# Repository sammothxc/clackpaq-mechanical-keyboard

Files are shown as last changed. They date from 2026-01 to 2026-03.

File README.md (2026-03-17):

CLACKPAQ
CLACKPAQ

A drop-in replacement mechanical keyboard for the Compaq Portable I/Plus foam and foil keyboard

## Specifications

- Controller: RP2040
- Switches: MX Cherry/Gateron Brown
- Keycaps: [Carbon PBT Double Shot Retro Orange](https://www.amazon.com/dp/B0D14Z76RH)
- Plate: FR4
- PCB: FR4, 2 layer, Hot-swappable
- Backlit

## Layout

### Modern

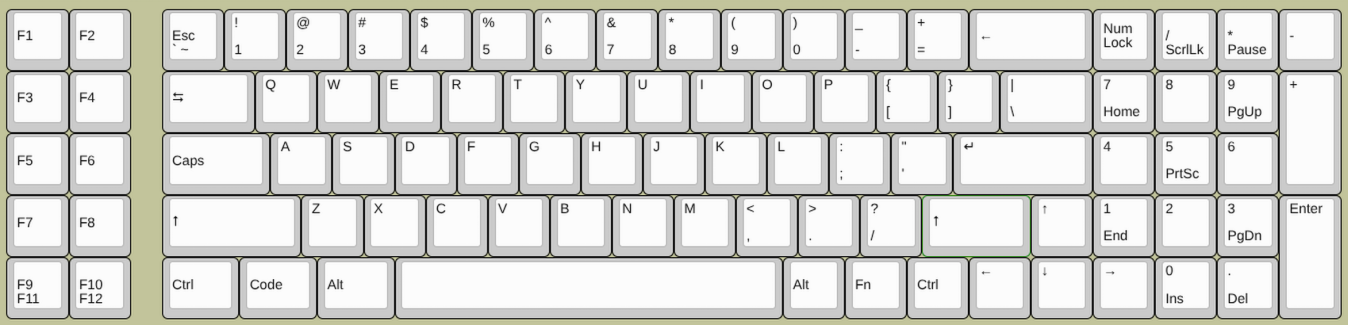
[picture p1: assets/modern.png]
Modern


### Compatible

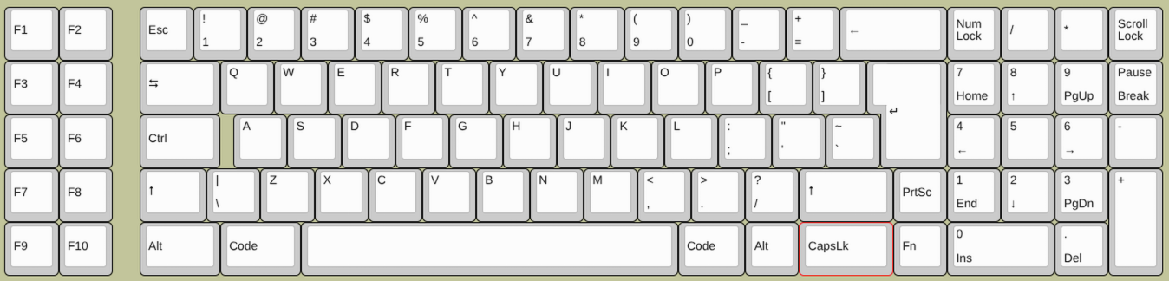
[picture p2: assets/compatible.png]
Compatible


### Original

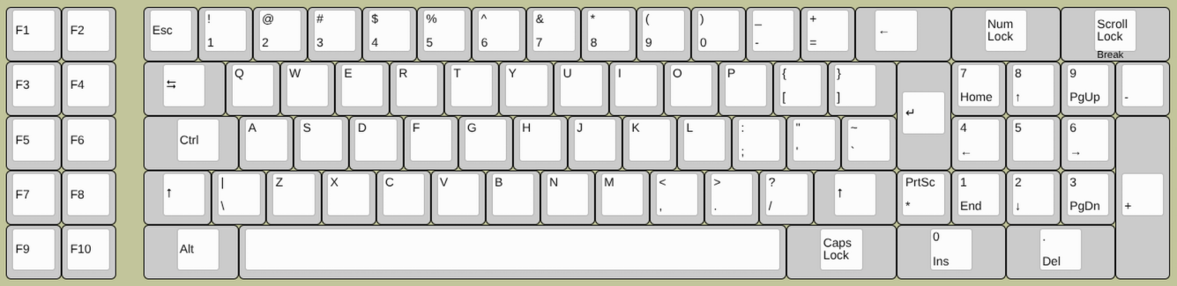
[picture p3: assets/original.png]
Original


### Spacing Differences
Original Keyboard Length: 18.75u / 357.18mm
Modern/Compatible Keyboard Layout Lengths: 10u / 361.95mm
Difference: 0.25u / 4.77mm

Row Specific Key Spacings
- Row 1
  - Total spacing w/ 18 keys (19 spaces): mm
  - Key Spacing: mm
- Row 2
  - 18 keys (19 spaces): mm
  - Key Spacing: mm
- Row 3
  - 17 keys (18 spaces): mm
  - Key Spacing: mm
- Row 4
  - 17 keys (18 spaces): mm
  - Key Spacing: mm
- Row 5
  - 13 keys (14 spaces): mm
  - Key Spacing: mm

## Pipe Dreams:
- Plates of other materials
- Acoustic foam

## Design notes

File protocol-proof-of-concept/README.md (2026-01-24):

# Clackpaq Firmware BETA

This firmware emulates the original Compaq Portable keyboard protocol, allowing you to send keystrokes to a Compaq Portable I or Portable Plus via serial commands.

## Hardware

**MCU:** Arduino Nano (ATmega328P @ 16MHz)
**Connections:**
  - D3 → CLK
  - D2 → DATA
  - GND → GND

## Protocol

Based on IBM PC/XT keyboard protocol with Compaq-specific timing:

- Idle state: CLK=HIGH, DATA=HIGH
- 9 bits per transmission: 1 start bit (always HIGH) + 8 data bits (LSB first)
- Host reads DATA on CLK falling edge
- Timing: ~358µs per byte transmission

## Serial Commands

| Command | Description |
|---|---|
| `BAT` | Send BAT completion code (0xAA) |
| `TEST` | Send 'A' key press and release |
| `SCOPE` | Send Enter make code (for oscilloscope testing) |
| `ENTER` | Send Enter key press and release |
| `MAKE xx` | Send make code (hex) |
| `BREAK xx` | Send break code (hex) |
| `RAW xx` | Send raw byte (hex) |
| `<text>` | Type text and press Enter |

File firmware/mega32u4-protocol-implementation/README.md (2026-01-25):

# Protocol Test Keyboard Matrix

Compaq Portable 1/Plus keyboard protocol emulator using a test keyboard matrix

## Hardware

- **MCU:** Elite-C ATmega32U4 (Pro Micro compatible)
- **Matrix:** 7 rows, 10 columns, 67 keys
- **XT Protocol Output:** 
  - CLK: Pin C6
  - DATA: Pin D4

## Pin Mapping

### Rows
| Row | Pin |
|-----|-----|
| 1 | F7 (A0) |
| 2 | B1 (15) |
| 3 | B2 (16) |
| 4 | F5 (A2) |
| 5 | F6 (A1) |
| 6 | F4 (A3) |
| 7 | B3 (14) |

### Columns
| Col | Pin |
|-----|-----|
| 1 | E6 (7) |
| 2 | B4 (8) |
| 3 | B5 (9) |
| 4 | B7 (11) |
| 5 | D5 |
| 6 | C7 (5) |
| 7 | F1 (A4) |
| 8 | F0 (A5) |
| 9 | B6 (10) |
| 10 | B0 |

### XT Interface
| Signal | Pin |
|---|-----|
| CLK | C6 (5) |
| DATA | D4 (4) |
| GND | GND |

## Keymap

### Base Layer
Standard QWERTY layout with:
- Arrow keys (Up/Down/Left/Right)
- Home, End, Page Up, Page Down
- Function key (Fn) for layer switching

### Function Layer (Fn+)
- Fn + 1-0 = F1-F10
- Fn + ~ = Escape  
- Fn + Backspace = Delete
- Fn + Home = Print Screen
- Fn + Caps = Scroll Lock

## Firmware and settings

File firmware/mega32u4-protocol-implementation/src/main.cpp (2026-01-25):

/*
* Protocol Test Keyboard Matrix
* For Elite-C Pro Micro (ATmega32U4)
* 
* Scans a 7x10 key matrix and outputs XT scancodes
* 
* License: CC BY-NC-SA 4.0
* https://github.com/sammothxc/clackpaq
*/

#include <Arduino.h>
#include "config.h"

// state vars
uint8_t keyState[ROWS][COLS];          // current debounced state
uint8_t lastKeyState[ROWS][COLS];      // previous state for edge detection
uint32_t lastDebounceTime[ROWS][COLS]; // debounce timers
bool fnPressed = false;                // fn layer active

// line control, open collector style
inline void clkHigh() {
  pinMode(XT_CLK, INPUT_PULLUP);
}

inline void clkLow() {
  pinMode(XT_CLK, OUTPUT);
  digitalWrite(XT_CLK, LOW);
}

inline void dataHigh() {
  pinMode(XT_DATA, INPUT_PULLUP);
}

inline void dataLow() {
  pinMode(XT_DATA, OUTPUT);
  digitalWrite(XT_DATA, LOW);
}

inline bool readClk() {
  pinMode(XT_CLK, INPUT_PULLUP);
  return digitalRead(XT_CLK);
}

void xt_write(uint8_t value, bool isBreak) {
  // wait for host to release CLK (not inhibiting)
  uint16_t timeout = 10000;
  while (!readClk() && timeout--) {
    delayMicroseconds(10);
  }
  if (timeout == 0) {
    Serial.println(F("Timeout: CLK held low by host"));
    return;
  }

  // ensure idle state
  clkHigh();
  dataHigh();
  delayMicroseconds(10);
  clkLow();
  delayMicroseconds(T_FIRST_CLK_LOW);

  // prep bit 0
  if (value & 0x01) {
    dataHigh();
  } else {
    dataLow();
  }
  clkHigh();
  value >>= 1;
  delayMicroseconds(T_CLK_HIGH);
    
  for (uint8_t i = 0; i < 7; i++) {
    clkLow();
    delayMicroseconds(T_CLK_LOW);

    // prep next bit
    if (value & 0x01) {
      dataHigh();
    } else {
      dataLow();
    }
    clkHigh();
    value >>= 1;
    delayMicroseconds(T_CLK_HIGH);
  }

  clkLow();
  delayMicroseconds(T_CLK_LOW);

  // DATA goes LOW for post-transmission hold
  dataLow();
  clkHigh();
    
  if (isBreak) {
    delayMicroseconds(T_POST_BREAK); // 500us for break codes
  } else {
    delayMicroseconds(T_POST_MAKE); // 640us for make codes
  }

  // return to idle
  dataHigh();
  delayMicroseconds(T_INTER_BYTE);
}

// wrappers
void xt_make(uint8_t scancode) {
    if (scancode == SC_NONE || scancode == SC_FN) return;
    xt_write(scancode, false);
}

void xt_break(uint8_t scancode) {
    if (scancode == SC_NONE || scancode == SC_FN) return;
    xt_write(scancode | 0x80, true);
}

void initMatrix() {
  for (uint8_t r = 0; r < ROWS; r++) {
    pinMode(rowPins[r], INPUT_PULLUP);
  }
  
  for (uint8_t c = 0; c < COLS; c++) {
    pinMode(colPins[c], INPUT_PULLUP);
  }
  
  for (uint8_t r = 0; r < ROWS; r++) {
    for (uint8_t c = 0; c < COLS; c++) {
      keyState[r][c] = 0;
      lastKeyState[r][c] = 0;
      lastDebounceTime[r][c] = 0;
    }
  }
}

void scanMatrix() {
  uint32_t now = millis();
  
  for (uint8_t r = 0; r < ROWS; r++) {
    pinMode(rowPins[r], OUTPUT);
    digitalWrite(rowPins[r], LOW);
    delayMicroseconds(5); // roughly the settle time
    
    for (uint8_t c = 0; c < COLS; c++) {
      uint8_t keyNum = keyMatrix[r][c];
      if (keyNum == 0) continue; // skip NC
      
      uint8_t reading = !digitalRead(colPins[c]);
      if (reading != lastKeyState[r][c]) {
        lastDebounceTime[r][c] = now;
      }
      
      if ((now - lastDebounceTime[r][c]) > DEBOUNCE_MS) {
        // state has been stable enough
        if (reading != keyState[r][c]) {
          keyState[r][c] = reading;
          
          uint8_t scancode;
          if (fnPressed && keyToScancodesFn[keyNum] != SC_NONE) {
            scancode = keyToScancodesFn[keyNum];
          } else {
            scancode = keyToScancode[keyNum];
          }
          
          // deal with fn key
          if (keyNum == 63) {
            fnPressed = reading;
          }
          else if (reading) {
            xt_make(scancode);
          } else {
            xt_break(scancode);
          }
        }
      }
      lastKeyState[r][c] = reading;
    }
    pinMode(rowPins[r], INPUT_PULLUP);
  }
}

void setup() {
  Serial.begin(9600);
  clkHigh();
  dataHigh();
  initMatrix();
  Serial.println(F("Clackpaq Keyboard Matrix Test Firmware"));
  delay(1000);
  xt_write(0xAA, false);
  Serial.println(F("Sent BAT (0xAA)"));
}

void loop() {
  // check if host is holding CLK low for >12.5ms, reset request
  if (!readClk()) {
    delay(15);
    if (!readClk()) {
      Serial.println(F("Host reset"));
      while (!readClk());
      delay(300);
      xt_write(0xAA, false);
    }
  }
  scanMatrix();
}

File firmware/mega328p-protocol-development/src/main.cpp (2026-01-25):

/*
* Protocol Proof of Concept
* For Arduino Nano (ATmega328P)
* 
* Based on oscilloscope captures and IBM 5155 Technical Reference
*
* License: CC BY-NC-SA 4.0
* https://github.com/sammothxc/clackpaq
*/

#include <Arduino.h>

#define XT_CLK  3
#define XT_DATA 2

// timing constants in microseconds
// adjusted for arduino overhead, target 358us total transmission
// digitalWrite/pinMode adds ~4-5us overhead per call, wish I could bitbang this stuff
#define T_FIRST_CLK_LOW   28    // first CLK pulse low time (target 42us with overhead)
#define T_CLK_LOW         14    // normal CLK low time (target 26us with overhead)
#define T_CLK_HIGH         7    // CLK high time (target 14us with overhead)
#define T_POST_MAKE      640    // DATA stays low after make code
#define T_POST_BREAK     500    // DATA stays low after break code
#define T_INTER_BYTE     200    // pause between bytes

// XT scan codes for standard ASCII characters
const uint8_t asciiToXt[128] = {
  // 0x00-0x0F: control characters
  0xFF, 0xFF, 0xFF, 0xFF, 0xFF, 0xFF, 0xFF, 0xFF,
  0x0E, 0x0F, 0x1C, 0xFF, 0xFF, 0x1C, 0xFF, 0xFF,  // BS=0x0E, TAB=0x0F, LF/CR=0x1C

  // 0x10-0x1F: more control characters  
  0xFF, 0xFF, 0xFF, 0xFF, 0xFF, 0xFF, 0xFF, 0xFF,
  0xFF, 0xFF, 0xFF, 0x01, 0xFF, 0xFF, 0xFF, 0xFF,  // ESC=0x01

  // 0x20-0x2F: space and punctuation
  0x39, 0x02, 0x28, 0x04, 0x05, 0x06, 0x08, 0x28,  // SP ! " # $ % & '
  0x0A, 0x0B, 0x09, 0x0D, 0x33, 0x0C, 0x34, 0x35,  // ( ) * + , - . /

  // 0x30-0x39: numbers 0-9
  0x0B, 0x02, 0x03, 0x04, 0x05, 0x06, 0x07, 0x08, 0x09, 0x0A,

  // 0x3A-0x40: more punctuation
  0x27, 0x27, 0x33, 0x0D, 0x34, 0x35, 0x03,        // : ; < = > ? @

  // 0x41-0x5A: uppercase A-Z
  0x1E, 0x30, 0x2E, 0x20, 0x12, 0x21, 0x22, 0x23, 0x17, 0x24,
  0x25, 0x26, 0x32, 0x31, 0x18, 0x19, 0x10, 0x13, 0x1F, 0x14,
  0x16, 0x2F, 0x11, 0x2D, 0x15, 0x2C,

  // 0x5B-0x60: even more punctuation
  0x1A, 0x2B, 0x1B, 0x07, 0x0C, 0x29,              // [ \ ] ^ _ `

  // 0x61-0x7A: lowercase a-z (same scancodes as uppercase)
  0x1E, 0x30, 0x2E, 0x20, 0x12, 0x21, 0x22, 0x23, 0x17, 0x24,
  0x25, 0x26, 0x32, 0x31, 0x18, 0x19, 0x10, 0x13, 0x1F, 0x14,
  0x16, 0x2F, 0x11, 0x2D, 0x15, 0x2C,

  // 0x7B-0x7F: lastly, punctuation
  0x1A, 0x2B, 0x1B, 0x29, 0x0E                     // { | } ~ DEL
};

// chars that require shift key
const bool needsShift[128] = {
  // 0x00-0x1F: control chars (no shift)
  0,0,0,0,0,0,0,0, 0,0,0,0,0,0,0,0,
  0,0,0,0,0,0,0,0, 0,0,0,0,0,0,0,0,

  // 0x20-0x2F: space ! " # $ % & ' ( ) * + , - . /
  0, 1, 1, 1, 1, 1, 1, 0, 1, 1, 1, 1, 0, 0, 0, 0,

  // 0x30-0x3F: 0-9 : ; < = > ?
  0,0,0,0,0,0,0,0,0,0, 1, 0, 1, 0, 1, 1,

  // 0x40-0x5A: @ and uppercase A-Z
  1, 1,1,1,1,1,1,1,1,1,1,1,1,1,1,1,1,1,1,1,1,1,1,1,1,1,1,

  // 0x5B-0x60: [ \ ] ^ _ `
  0, 0, 0, 1, 1, 0,

  // 0x61-0x7A: lowercase a-z
  0,0,0,0,0,0,0,0,0,0,0,0,0,0,0,0,0,0,0,0,0,0,0,0,0,0,

  // 0x7B-0x7F: { | } ~
  1, 1, 1, 1, 0
};

#define XT_SHIFT 0x2A

void xt_write(uint8_t value, bool isBreak);
void xt_make(uint8_t scancode);
void xt_break(uint8_t scancode);
void xt_key(uint8_t scancode);
void sendChar(char c);
void sendString(const char* str);

// line control, open collector style
inline void clkHigh() {
  pinMode(XT_CLK, INPUT_PULLUP);
}

inline void clkLow() {
  pinMode(XT_CLK, OUTPUT);
  digitalWrite(XT_CLK, LOW);
}

inline void dataHigh() {
  pinMode(XT_DATA, INPUT_PULLUP);
}

inline void dataLow() {
  pinMode(XT_DATA, OUTPUT);
  digitalWrite(XT_DATA, LOW);
}

inline bool readClk() {
  pinMode(XT_CLK, INPUT_PULLUP);
  return digitalRead(XT_CLK);
}

void xt_write(uint8_t value, bool isBreak) {
  // wait for host to release CLK (not inhibiting)
  uint16_t timeout = 10000;
  while (!readClk() && timeout--) {
    delayMicroseconds(10);
  }
  if (timeout == 0) {
    Serial.println(F("Timeout: CLK held low by host"));
    return;
  }

  // ensure idle state
  clkHigh();
  dataHigh();
  delayMicroseconds(10);
  clkLow();
  delayMicroseconds(T_FIRST_CLK_LOW);

  // prep bit 0
  if (value & 0x01) {
    dataHigh();
  } else {
    dataLow();
  }
  clkHigh();
  value >>= 1;
  delayMicroseconds(T_CLK_HIGH);

  for (uint8_t i = 0; i < 7; i++) {
    clkLow();
    delayMicroseconds(T_CLK_LOW);

    // prep next bit
    if (value & 0x01) {
      dataHigh();
    } else {
      dataLow();
    }
    clkHigh();
    value >>= 1;
    delayMicroseconds(T_CLK_HIGH);
  }

  clkLow();
  delayMicroseconds(T_CLK_LOW);

  // DATA goes LOW for post-transmission hold
  dataLow();
  clkHigh();

  if (isBreak) {
    delayMicroseconds(T_POST_BREAK); // 500us for break codes
  } else {
    delayMicroseconds(T_POST_MAKE); // 640us for make codes
  }

  // return to idle
  dataHigh();
  delayMicroseconds(T_INTER_BYTE);
}

// wrappers
void xt_make(uint8_t scancode) {
  xt_write(scancode, false);
}

void xt_break(uint8_t scancode) {
  xt_write(scancode | 0x80, true);
}

void xt_key(uint8_t scancode) {
  xt_make(scancode);
  delay(10);
  xt_break(scancode);
}

// send char as XT scancode
void sendChar(char c) {
  if (c < 0 || c > 127) return;

  uint8_t scancode = asciiToXt[(uint8_t)c];
  if (scancode == 0xFF) return;

  bool shift = needsShift[(uint8_t)c];

  if (shift) {
    xt_make(XT_SHIFT);
  }

  xt_key(scancode);

  if (shift) {
    xt_break(XT_SHIFT);
  }
}

void sendString(const char* str) {
  while (*str) {
    sendChar(*str++);
    delay(10);
  }
}

String inputBuffer = "";

void setup() {
  Serial.begin(9600);
  clkHigh();
  dataHigh();
  Serial.println(F("Clackpaq Compaq Portable XT Protocol Tester"));
  Serial.println(F("Idle: CLK=HIGH, DATA=HIGH"));
  Serial.println(F("Commands: BAT, RAW xx, MAKE xx, BREAK xx, TEST, SCOPE"));
  Serial.println(F("Or type text and press Enter"));
  Serial.println();
  delay(1000); // POR delay
  xt_write(0xAA, false); // BAT completion code
  Serial.println(F("Sent BAT (0xAA) - keyboard ready"));
}
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

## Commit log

2026-01-26 wrong pin defs
2026-01-26 raw protocol working on rp2040, transistor logic not working yet
    [rp2040-clackpaq-firmware.c]
2026-03-11 kicad project boilerplate files
    [clackpaq-mechanical-keyboard.kicad_pcb, clackpaq-mechanical-keyboard.kicad_sch]
2026-03-12 modern layout
    [clackpaq-compatible.kicad_pcb, clackpaq-compatible.kicad_sch, clackpaq-mechanical-keyboard.kicad_sch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]
